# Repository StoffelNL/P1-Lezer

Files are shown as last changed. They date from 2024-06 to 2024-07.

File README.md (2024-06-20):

Een P1-Lezer voor Home Assistant
========

Dit is een simpele P1-lezer voor een 'slimme meter' die integreert met Home Assistant. De lezer is gebaseerd op een WiFi-controller zodat je 'm draadloos kunt verbinden met een home automation-systeem. De enige draad die je nodig hebt is een kabeltje om de lezer op de P1-poort van je slimme meter aan te sluiten.

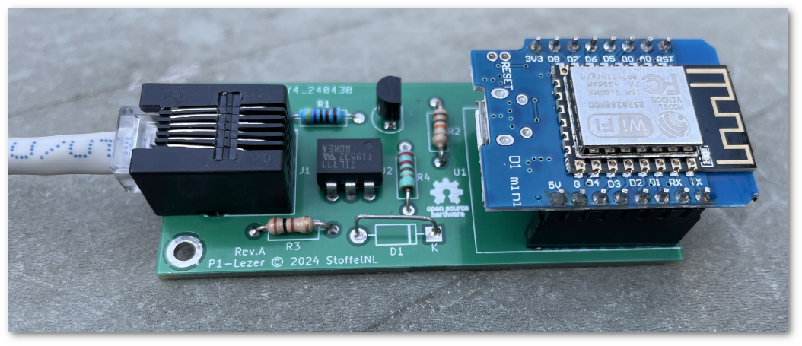
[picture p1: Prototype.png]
Prototype


Onderdelen
----------
Je vindt hier:
- een KiCad-project met een schema, een printplaat en Gerber-bestanden
waarmee je die print kunt laten maken.
- een YAML-bestand voor ESPHome (https://esphome.io/) waarmee je de Wifi-controller kunt programmeren.

### De hardware
Deze P1-lezer is gebaseerd op een ESP8266 WiFi-controller, de WeMos D1 Mini. Dat is een kleine goedkope microcontroller die in dit geval het seriële datasignaal van de slimme meter via een WiFi-verbinding naar je home-automation stuurt.
Je sluit de lezer met een zes-aderige RJ12-kabel aan op de meter.

In de P1-aansluiting worden vijf van de zes pinnen gebruikt (in de volgorde van de RJ12):

1. +5 Volt
2. Data Request
3. Data Ground
4. Not connected
5. Data Transmit
6. Ground

Deze lezer gebruikt ze allemaal. De 5 volt wordt gebruikt als voeding. De Data Request kan je gebruiken om het data-signaal te starten en stoppen (maar het hoeft niet). En de Data Transmit-lijn levert alle meetwaarden. De twee ground-aansluitingen worden aan elkaar gekoppeld.

### De software
Met het YAML-bestand kan je de ESP8266 programmeren. Je kunt dat doen vanuit Home Assistant door de ESPHome-integratie toe te voegen. Een andere methode is de command-line-versie van ESPHome installeren. Dan heb je ook nog Python nodig.

In de YAML-code in deze repo is ook het uitlezen van de gasmeter opgenomen. Heb je geen gekoppelde gasmeter dan kan je dat stukje uit de YAML verwijderen.
Voordat je de D1 Mini gaat progammeren moet je eerst de naam van jouw WiFi-netwerk invullen, met het bijbehorende wachtwoord.

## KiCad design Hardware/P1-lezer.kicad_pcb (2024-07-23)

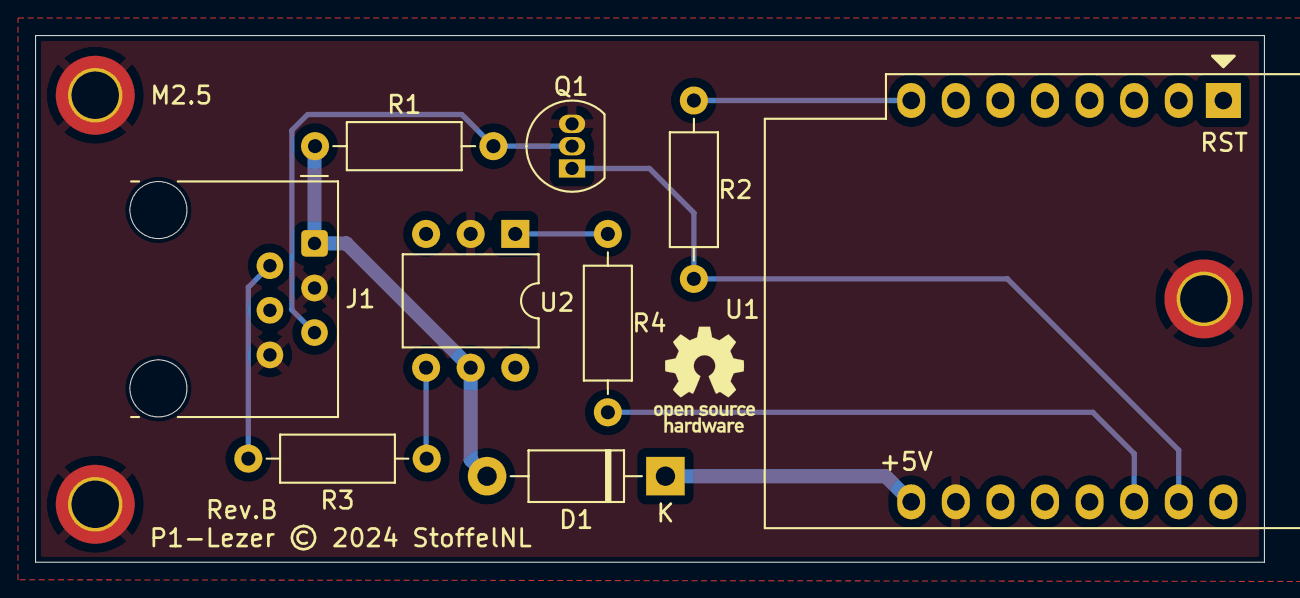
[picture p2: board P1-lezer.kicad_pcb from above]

Board: 2 copper layers, 70.0 x 30.0 mm, 13 parts (0 on the bottom side), 10 nets.

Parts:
D1: 1N5817; D_DO-41_SOD81_P10.16mm_Horizontal
J1: RJ12; RJ12_Amphenol_54601-x06_Horizontal
M2.5: MountingHole_2.7mm_M2.5_ISO7380_Pad_TopBottom
MH2, MH3: MountingHole_2.7mm_M2.5_ISO7380_Pad_TopBottom
OpenSourceHarware-logo: OSHW-Logo_5.7x6mm_SilkScreen
Q1: BC547; TO-92_Inline
R1: 4k7; R_Axial_DIN0207_L6.3mm_D2.5mm_P10.16mm_Horizontal
R2: 10k; R_Axial_DIN0207_L6.3mm_D2.5mm_P10.16mm_Horizontal
R3: 100; R_Axial_DIN0207_L6.3mm_D2.5mm_P10.16mm_Horizontal
R4: 220; R_Axial_DIN0207_L6.3mm_D2.5mm_P10.16mm_Horizontal
U1: WeMos_D1_mini; WEMOS_D1_mini_light
U2: CNY17-1; DIP-6_W7.62mm

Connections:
+3.3V: R2.1, U1.8 (3V3)
+5V: D1.2 (A), J1.1, R1.1, U2.5
GND: J1.3, J1.6, M2.5.1, MH2.1, MH3.1, Q1.3 (E), U1.10 (GND), U2.2
unnamed: D1.1 (K), U1.9 (5V)
unnamed: J1.2, R3.2
unnamed: J1.5, Q1.2 (B), R1.2
unnamed: Q1.1 (C), R2.2, U1.15 (RX)
unnamed: R3.1, U2.4
unnamed: R4.1, U2.1
Req: R4.2, U1.14 (SCL/D1)

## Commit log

2024-04-23 Revisie toegevoegd op pcb
    [P1-lezer.kicad_pcb, P1-lezer.kicad_sch]
2024-04-23 Beginnetje van de README.md
2024-04-29 re-routed signal slightly, checked RJ12 dimensions, regenerated gerbers.
    [P1-lezer-B_Cu.gbl, P1-lezer-B_Mask.gbs, P1-lezer-B_Paste.gbp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]
2024-05-04 Added dimension lines.
    [P1-lezer.kicad_pcb]
2024-05-04 Added github-URL
    [P1-lezer.kicad_pcb]
2024-05-05 Locked mounting holes
    [P1-lezer.kicad_pcb]
2024-05-12 Changed board to d1 mini
2024-05-12 Added list with different track widths
2024-05-12 Moved the request output from D4 to D5.
    [P1-lezer.kicad_sch]
2024-05-12 Moved request line to D1 and rerouted the board to match this change.
    [P1-lezer.kicad_pcb, P1-lezer.kicad_sch]
2024-05-12 Regenerated gerbers
    [P1-lezer-B_Cu.gbl, P1-lezer-B_Mask.gbs, P1-lezer-B_Paste.gbp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]
2024-05-12 Waarschuwing weer verwijderd na aanpassingen aan schema, print en yaml.
2024-06-20 Plaatje Prototype.png toegevoegd.
2024-06-20 Optocoupler aangepast naar CNY17-1
    [P1-lezer.kicad_pcb, P1-lezer.kicad_sch]
2024-07-23 RST en +5V markering toegevoegd aan pcb om orientatie D1 Mini te verduidelijken.
    [P1-lezer.kicad_pcb]

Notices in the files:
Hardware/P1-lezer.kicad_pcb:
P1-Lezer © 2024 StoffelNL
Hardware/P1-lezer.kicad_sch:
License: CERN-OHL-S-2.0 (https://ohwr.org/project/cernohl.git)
